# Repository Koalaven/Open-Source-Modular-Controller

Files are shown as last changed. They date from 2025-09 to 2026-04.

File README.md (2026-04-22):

# Open Source Modular Controller

Using a modular, reconfigurable hardware architecture to create a customizable USB HID game controller.

## Project Details

The Open Source Modular Controller project is a fully modular and customizable gaming input system. Users can freely rearrange joysticks, buttons, and future input modules on a set of interchangeable receiver boards to build a layout that fits their gameplay style, ergonomic needs, or accessibility requirements.

The controller connects over USB and is recognized as a standard Human Interface Device (HID) with no additional drivers required.



## Current State

The current prototype includes:
- A functional ESP32‑S3‑based main controller
- Hot-swappable joystick and button modules
- Receiver boards that can be placed anywhere in the 3D‑printed shell
- USB HID communication via TinyUSB

The system operates as a recognized USB gamepad on Windows. Some hardware issues were identified and corrected in updated revisions.

## Project Structure

The repository is organized as follows:
1. **Firmware** – ESP32‑S3 code handling HID communication and module input processing.  
   *Link: [Firmware](/Controller%20Code/Firmware.md)*
2. **Software** – PC‑side utilities or test scripts (coming soon).  
3. **Hardware** – KiCad project files, schematics, PCBs, and 3D‑printed shell models.  
   *Link: [Hardware](/Hardware/Hardware.md)*
4. **Documentation** – Assembly instructions, diagrams, semester report, and testing notes.  
   *Link: [Documentation](/Documents/Documents.md)*

## Features

- Modular input modules (buttons, joystick, future sensors)
- Repositionable input layout using multiple receiver boards
- ESP32‑S3 native USB HID support
- Open‑source hardware and firmware
- Premade 3D‑printable ergonomic controller shell

## System Architecture

Core system components include:
- **Receiver boards** distributing power, signals, and micro-controller
- **Module boards** for inputs (joystick/button)
- **3D‑printed enclosure** with heat‑set inserts for secure mounting

USB HID enumeration and report handling are implemented using TinyUSB. Modules communicate through standardized connectors to the controller board.

## Bill of Materials
A full BOM including the ESP32‑S3 boards, connector sets, resistors, capacitors, PCBs, wire, and 3D‑printed components is provided in the documentation.  
*[BOM](/Documents/BOM.md)*

## Tools Used
### Software
- Arduino IDE
- KiCad
- Fusion (frame design)
- GitHub Desktop
- Cura slicer

### Hardware
- 3D printer
- Soldering iron
- Hot air station
- Multimeter
- Tweezers

## Assembly Overview
1. Gather materials (refer to BOM).  
2. Order PCBs (Gerber files included).  
3. 3D print shell and module housings.  
4. Clean and prepare boards.  
5. Solder components (headers, ESP32 module, connectors, buttons/joysticks).  
6. Upload firmware via Arduino IDE.  
7. Install modules into the shell.  
8. Test controller.  

[Full assembly guide](/Documents/Assembly%20guide.md)

## What the Project Could Use Next
1. On‑board processing for more advanced input mapping
2. PCB adjustment and testing
3. Wireless mode using Bluetooth HID
4. Additional module types (battery, gyroscope, sliders, touchpads)

## Semester End Report
For the Enterprise Program at Michigan Tech there is a end of semester report for the project to summarize the progress of the project. [Link](/Documents/Open%20Source%20Modular%20Controller%20Fall%202025%20Final%20Report.pdf)

## Acknowledgements
This project is supported by the Open Source Hardware Enterprise at Michigan Technological University.

## Helpful Links
- [TinyUSB](https://docs.tinyusb.org/en/latest/)
- [Gamepad tester](https://hardwaretester.com/gamepad)

## References

[GitHub Doc](https://docs.github.com/en/get-started/writing-on-github/getting-started-with-writing-and-formatting-on-github/basic-writing-and-formatting-syntax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)

[Alpakka conroller](https://inputlabs.io/alpakka)

[Proteus ControllerTM kit](https://byowave.com/products/proteus-controller )

[Thrustmaster](https://eshop.thrustmaster.com/en_us/gamepads/pc.html)

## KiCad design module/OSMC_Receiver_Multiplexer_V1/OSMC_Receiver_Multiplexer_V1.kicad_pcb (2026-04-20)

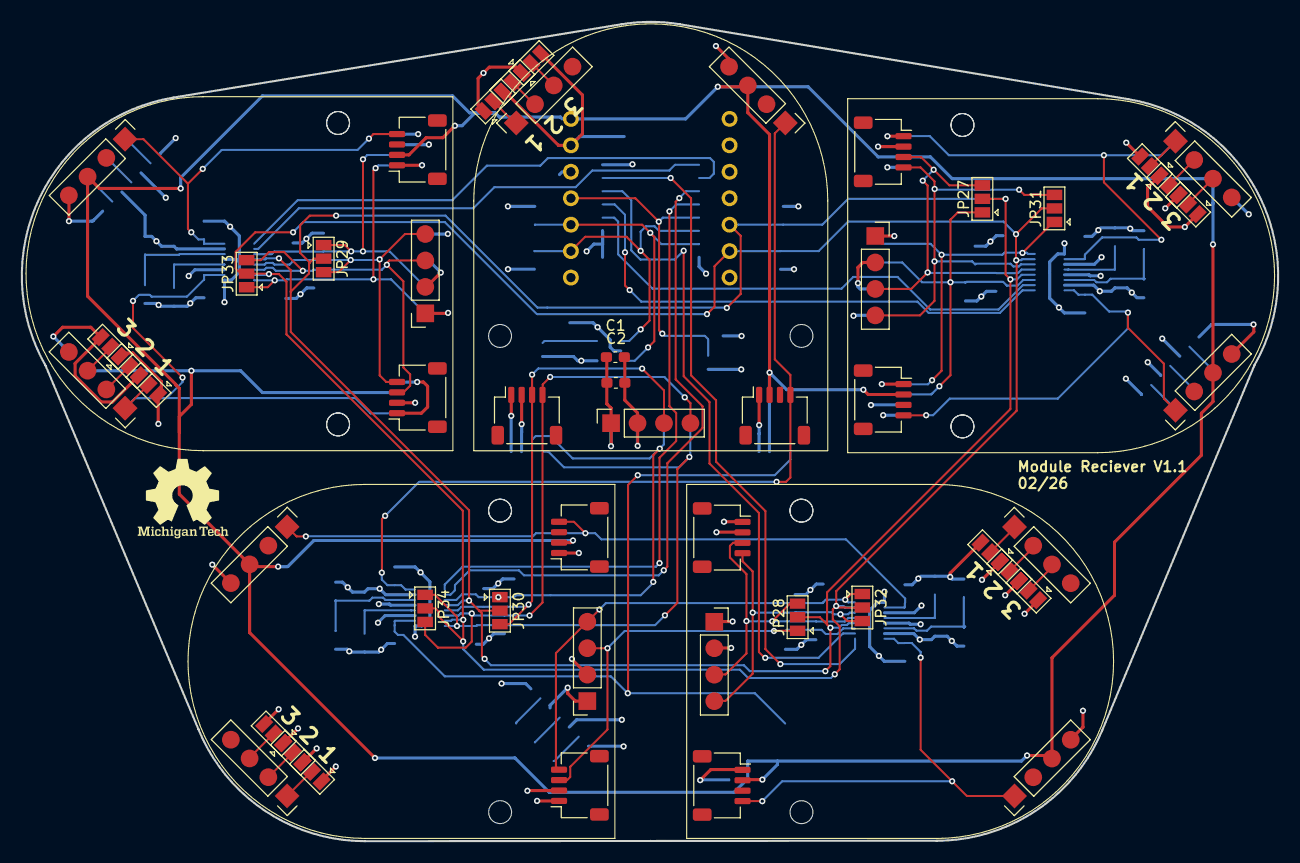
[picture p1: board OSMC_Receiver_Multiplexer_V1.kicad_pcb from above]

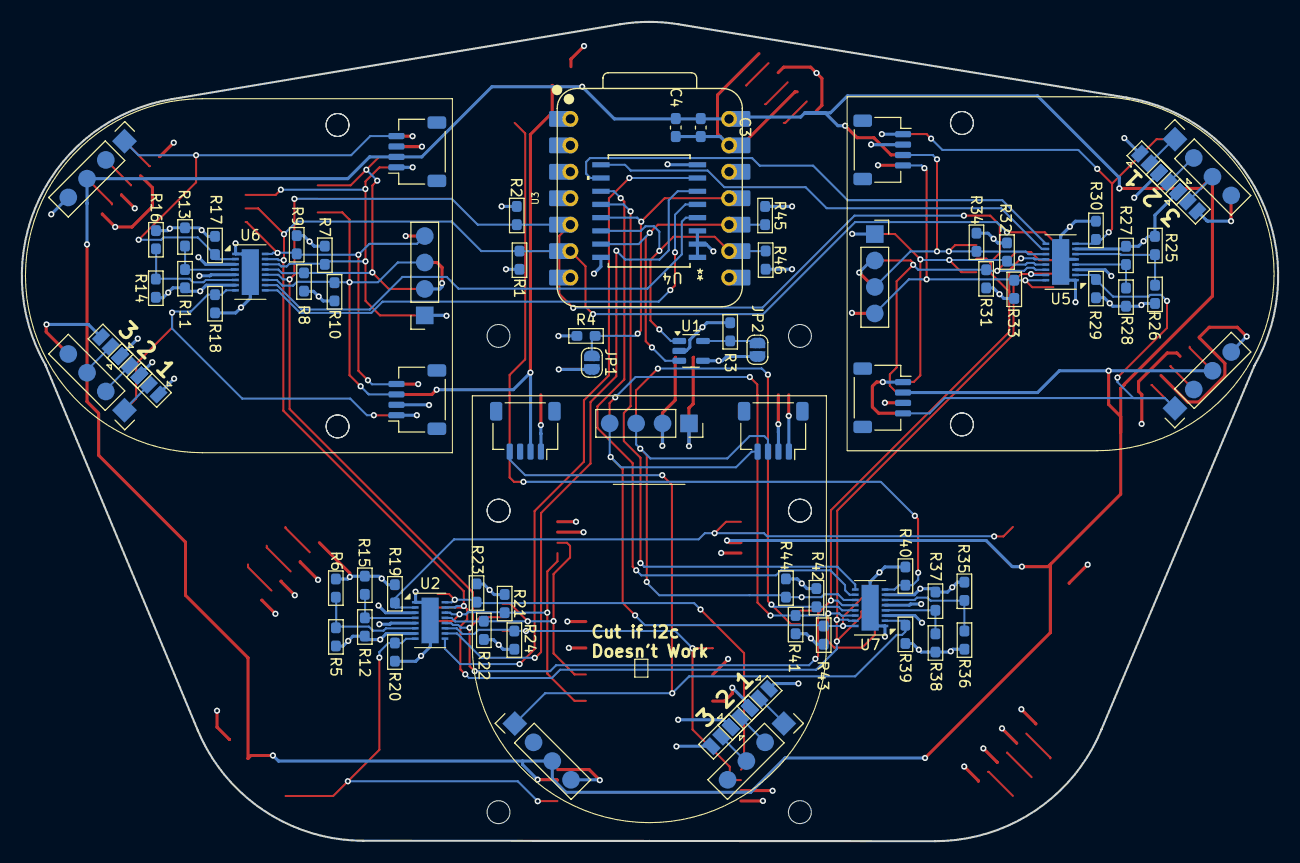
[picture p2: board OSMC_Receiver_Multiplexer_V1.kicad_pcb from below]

Board: 4 copper layers, 120.7 x 78.7 mm, 99 parts (69 on the bottom side), 73 nets.

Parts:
C1, C2: .1 u; C_0603_1608Metric_Pad1.08x0.95mm_HandSolder
C3, C4: C; C_0603_1608Metric_Pad1.08x0.95mm_HandSolder
JP1: int; SolderJumper-2_P1.3mm_Open_RoundedPad1.0x1.5mm
JP2: WP; SolderJumper-2_P1.3mm_Open_RoundedPad1.0x1.5mm
JP3, JP4, JP5, JP6, JP7, JP8, JP9, JP10, JP11, JP12, JP13, JP14, JP15, JP16, JP17, JP18, JP19, JP20, JP21, JP22, JP23, JP24, JP25, JP26, JP27, JP28, JP29, JP30, JP31, JP32, JP33, JP34: SolderJumper_3_Open; SolderJumper-3_P1.3mm_Open_Pad1.0x1.5mm
R1, R2, R7, R8, R9, R10, R17, R18, R19, R20, R21, R22, R23, R24, R29, R30, R31, R32, R33, R34, R39, R40, R41, R42, R43, R44, R45, R46: 10k; R_0603_1608Metric_Pad1.05x0.95mm_HandSolder
R3, R4: 100k; R_0603_1608Metric_Pad1.05x0.95mm_HandSolder
R5, R11: 976k; R_0603_1608Metric_Pad1.05x0.95mm_HandSolder
R6: 182k; R_0603_1608Metric_Pad1.05x0.95mm_HandSolder
R12: 1M; R_0603_1608Metric_Pad1.05x0.95mm_HandSolder
R13: 102k; R_0603_1608Metric_Pad1.05x0.95mm_HandSolder
R14: R; R_0603_1608Metric_Pad1.05x0.95mm_HandSolder
R15: 280k; R_0603_1608Metric_Pad1.05x0.95mm_HandSolder
R16: 0; R_0603_1608Metric_Pad1.05x0.95mm_HandSolder
R25, R27, R35, R37: 1000k; R_0603_1608Metric_Pad1.05x0.95mm_HandSolder
R26: 392k; R_0603_1608Metric_Pad1.05x0.95mm_HandSolder
R28: 523k; R_0603_1608Metric_Pad1.05x0.95mm_HandSolder
R36: 681k; R_0603_1608Metric_Pad1.05x0.95mm_HandSolder
R38: 887k; R_0603_1608Metric_Pad1.05x0.95mm_HandSolder
U1: 24AA02-OT; SOT-23-5
U2, U5, U6, U7: LTC4317; DFN-16-1EP_3x5mm_P0.5mm_EP1.66x4.4mm
U3: XIAO-ESP32-S3-DIP
U4: PCF8574DWR; DW16-L
U13, U14, U15, U16, U17, U18, U19, U20: OSMC Module Board; Module standard pin large outline

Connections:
+5V: C3.1, C4.1, U3.14 (5V), U13.10 (5V), U13.15 (5V), U14.10 (5V), U14.15 (5V), U15.10 (5V), U15.15 (5V), U16.10 (5V), U16.15 (5V), U17.10 (5V), U17.15 (5V), U18.10 (5V), U18.15 (5V), U19.10 (5V), U19.15 (5V), U20.10 (5V), U20.15 (5V)
/INT: JP1.1 (A), R4.2, U3.11 (PA6_A10_D10_MOSI), U4.13 (~INT)
/Modules/EN0: R18.2, U6.8 (ENABLE1), U13.12 (Det), U13.13 (Det)
/Modules/EN1: R17.2, U6.2 (ENABLE2), U15.12 (Det), U15.13 (Det)
/Modules/EN2: R20.2, U2.8 (ENABLE1), U16.12 (Det), U16.13 (Det)
/Modules/EN3: R19.2, U2.2 (ENABLE2), U18.12 (Det), U18.13 (Det)
/Modules/EN4: R30.2, U5.8 (ENABLE1), U17.12 (Det), U17.13 (Det)
/Modules/EN5: R29.2, U5.2 (ENABLE2), U20.12 (Det), U20.13 (Det)
/Modules/EN6: R40.2, U7.8 (ENABLE1), U14.12 (Det), U14.13 (Det)
/Modules/EN7: R39.2, U7.2 (ENABLE2), U19.12 (Det), U19.13 (Det)
/Modules/P0: U4.4 (P0), U6.10 (READY1)
/Modules/P1: U4.5 (P1), U6.9 (READY2)
/Modules/P2: U2.10 (READY1), U4.6 (P2)
/Modules/P3: U2.9 (READY2), U4.7 (P3)
/Modules/P4: U4.9 (P4), U5.10 (READY1)
/Modules/P5: U4.10 (P5), U5.9 (READY2)
/Modules/P6: U4.11 (P6), U7.10 (READY1)
/Modules/P7: U4.12 (P7), U7.9 (READY2)
/Modules/SCL0: JP31.3 (B), R7.2, U6.14 (SCLOUT1), U13.4 (SCL), U13.8 (SCL)
/Modules/SCL1: JP31.1 (A), R9.2, U6.16 (SCLOUT2), U15.4 (SCL), U15.8 (SCL)
/Modules/SCL2: JP32.3 (B), R21.2, U2.14 (SCLOUT1), U16.4 (SCL), U16.8 (SCL)
/Modules/SCL3: JP32.1 (A), R23.2, U2.16 (SCLOUT2), U18.4 (SCL), U18.8 (SCL)
/Modules/SCL4: JP33.3 (B), R31.2, U5.14 (SCLOUT1), U17.3 (SDA), U17.7 (SDA)
/Modules/SCL5: JP33.1 (A), R33.2, U5.16 (SCLOUT2), U20.4 (SCL), U20.8 (SCL)
/Modules/SCL6: JP34.3 (B), R41.2, U7.14 (SCLOUT1), U14.4 (SCL), U14.8 (SCL)
/Modules/SCL7: JP34.1 (A), R43.2, U7.16 (SCLOUT2), U19.4 (SCL), U19.8 (SCL)
/Modules/SDA0: JP27.3 (B), R8.2, U6.13 (SDAOUT1), U13.3 (SDA), U13.7 (SDA)
/Modules/SDA1: JP27.1 (A), R10.2, U6.11 (SDAOUT2), U15.3 (SDA), U15.7 (SDA)
/Modules/SDA2: JP28.3 (B), R22.2, U2.13 (SDAOUT1), U16.3 (SDA), U16.7 (SDA)
/Modules/SDA3: JP28.1 (A), R24.2, U2.11 (SDAOUT2), U18.3 (SDA), U18.7 (SDA)
/Modules/SDA4: JP29.3 (B), R32.2, U5.13 (SDAOUT1), U17.4 (SCL), U17.8 (SCL)
/Modules/SDA5: JP29.1 (A), R34.2, U5.11 (SDAOUT2), U20.3 (SDA), U20.7 (SDA)
/Modules/SDA6: JP30.3 (B), R42.2, U7.13 (SDAOUT1), U14.3 (SDA), U14.7 (SDA)
/Modules/SDA7: JP30.1 (A), R44.2, U7.11 (SDAOUT2), U19.3 (SDA), U19.7 (SDA)
/SCL: JP31.2 (C), JP32.2 (C), JP33.2 (C), JP34.2 (C), R1.2, U2.15 (SCLIN), U3.6 (PA9_A5_D5_SCL), U5.15 (SCLIN), U6.15 (SCLIN), U7.15 (SCLIN)
/SCL1: R46.2, U1.1 (SCL), U3.9 (PA7_A8_D8_SCK), U4.14 (SCL)
/SDA: JP27.2 (C), JP28.2 (C), JP29.2 (C), JP30.2 (C), R2.2, U2.12 (SDAIN), U3.5 (PA8_A4_D4_SDA), U5.12 (SDAIN), U6.12 (SDAIN), U7.12 (SDAIN)
/SDA1: R45.2, U1.3 (SDA), U3.10 (PA5_A9_D9_MISO), U4.15 (SDA)
/wp: JP2.1 (A), R3.2, U1.5 (WP)
GND: C1.2, C2.2, C3.2, C4.2, JP3.3 (B), JP4.3 (B), JP5.3 (B), JP6.3 (B), JP7.3 (B), JP8.3 (B), JP9.3 (B), JP10.3 (B), JP11.3 (B), JP12.3 (B), JP13.3 (B), JP14.3 (B), JP15.3 (B), JP16.3 (B), JP17.3 (B), JP18.3 (B), JP19.3 (B), JP20.3 (B), JP21.3 (B), JP22.3 (B), JP23.3 (B), JP24.3 (B), JP25.3 (B), JP26.3 (B), R3.1, R4.1, R6.2, R13.2, R15.2, R16.2, R17.1, R18.1, R19.1, R20.1, R26.2, R28.2, R29.1, R30.1, R36.2, R38.2, R39.1, R40.1, U1.2 (V_{SS}), U2.1 (GND), U2.3 (XORH2), U2.5 (XORH1), U2.17 (EP), U3.13 (GND), U4.1 (A0), U4.2 (A1), U4.3 (A2), U4.8 (GND), U5.1 (GND), U5.3 (XORH2), U5.5 (XORH1), U5.17 (EP), U6.1 (GND), U6.3 (XORH2), U6.5 (XORH1), U6.17 (EP), U7.1 (GND), U7.3 (XORH2), U7.5 (XORH1), U7.17 (EP), U13.1 (Gnd), U13.5 (Gnd), U13.9 (Gnd), U13.16 (GND), U14.1 (Gnd), U14.5 (Gnd), U14.9 (Gnd), U14.16 (GND), U15.1 (Gnd), U15.5 (Gnd), U15.9 (Gnd), U15.16 (GND), U16.1 (Gnd), U16.5 (Gnd), U16.9 (Gnd), U16.16 (GND), U17.1 (Gnd), U17.5 (Gnd), U17.9 (Gnd), U17.16 (GND), U18.1 (Gnd), U18.5 (Gnd), U18.9 (Gnd), U18.16 (GND), U19.1 (Gnd), U19.5 (Gnd), U19.9 (Gnd), U19.16 (GND), U20.1 (Gnd), U20.5 (Gnd), U20.9 (Gnd), U20.16 (GND)
unnamed: JP3.2 (C), U16.18 (A3)
unnamed: JP4.2 (C), U16.19 (A2)
unnamed: JP5.2 (C), U16.20 (A1)
unnamed: JP6.2 (C), U15.18 (A3)
unnamed: JP7.2 (C), U15.19 (A2)
unnamed: JP8.2 (C), U15.20 (A1)
unnamed: JP9.2 (C), U13.18 (A3)
unnamed: JP10.2 (C), U13.19 (A2)
unnamed: JP11.2 (C), U13.20 (A1)
unnamed: JP12.2 (C), U18.18 (A3)
unnamed: JP13.2 (C), U18.19 (A2)
unnamed: JP14.2 (C), U18.20 (A1)
unnamed: JP15.2 (C), U19.18 (A3)
unnamed: JP16.2 (C), U19.19 (A2)
unnamed: JP17.2 (C), U19.20 (A1)
unnamed: JP18.2 (C), U17.18 (A3)
unnamed: JP19.2 (C), U17.19 (A2)
unnamed: JP20.2 (C), U17.20 (A1)
unnamed: JP21.2 (C), U20.18 (A3)
unnamed: JP22.2 (C), U20.19 (A2)
unnamed: JP23.2 (C), U20.20 (A1)
unnamed: JP24.2 (C), U14.18 (A3)
unnamed: JP25.2 (C), U14.19 (A2)
unnamed: JP26.2 (C), U14.20 (A1)
unnamed: R5.2, R6.1, U2.6 (XORL1)
unnamed: R12.2, R15.1, U2.4 (XORL2)
unnamed: R25.2, R26.1, U5.6 (XORL1)
unnamed: R27.2, R28.1, U5.4 (XORL2)
unnamed: R14.2, R16.1, U6.6 (XORL1)
unnamed: R11.2, R13.1, U6.4 (XORL2)
unnamed: R35.2, R36.1, U7.6 (XORL1)
unnamed: R37.2, R38.1, U7.4 (XORL2)
VDD: C1.1, C2.1, JP1.2 (B), JP2.2 (B), JP3.1 (A), JP4.1 (A), JP5.1 (A), JP6.1 (A), JP7.1 (A), JP8.1 (A), JP9.1 (A), JP10.1 (A), JP11.1 (A), JP12.1 (A), JP13.1 (A), JP14.1 (A), JP15.1 (A), JP16.1 (A), JP17.1 (A), JP18.1 (A), JP19.1 (A), JP20.1 (A), JP21.1 (A), JP22.1 (A), JP23.1 (A), JP24.1 (A), JP25.1 (A), JP26.1 (A), R1.1, R2.1, R5.1, R7.1, R8.1, R9.1, R10.1, R11.1, R12.1, R14.1, R21.1, R22.1, R23.1, R24.1, R25.1, R27.1, R31.1, R32.1, R33.1, R34.1, R35.1, R37.1, R41.1, R42.1, R43.1, R44.1, R45.1, R46.1, U1.4 (V_{CC}), U2.7 (VCC), U3.12 (3V3), U4.16 (VDD), U5.7 (VCC), U6.7 (VCC), U7.7 (VCC), U13.2 (Vdd), U13.6 (Vdd), U14.2 (Vdd), U14.6 (Vdd), U15.2 (Vdd), U15.6 (Vdd), U16.2 (Vdd), U16.6 (Vdd), U17.2 (Vdd), U17.6 (Vdd), U18.2 (Vdd), U18.6 (Vdd), U19.2 (Vdd), U19.6 (Vdd), U20.2 (Vdd), U20.6 (Vdd)

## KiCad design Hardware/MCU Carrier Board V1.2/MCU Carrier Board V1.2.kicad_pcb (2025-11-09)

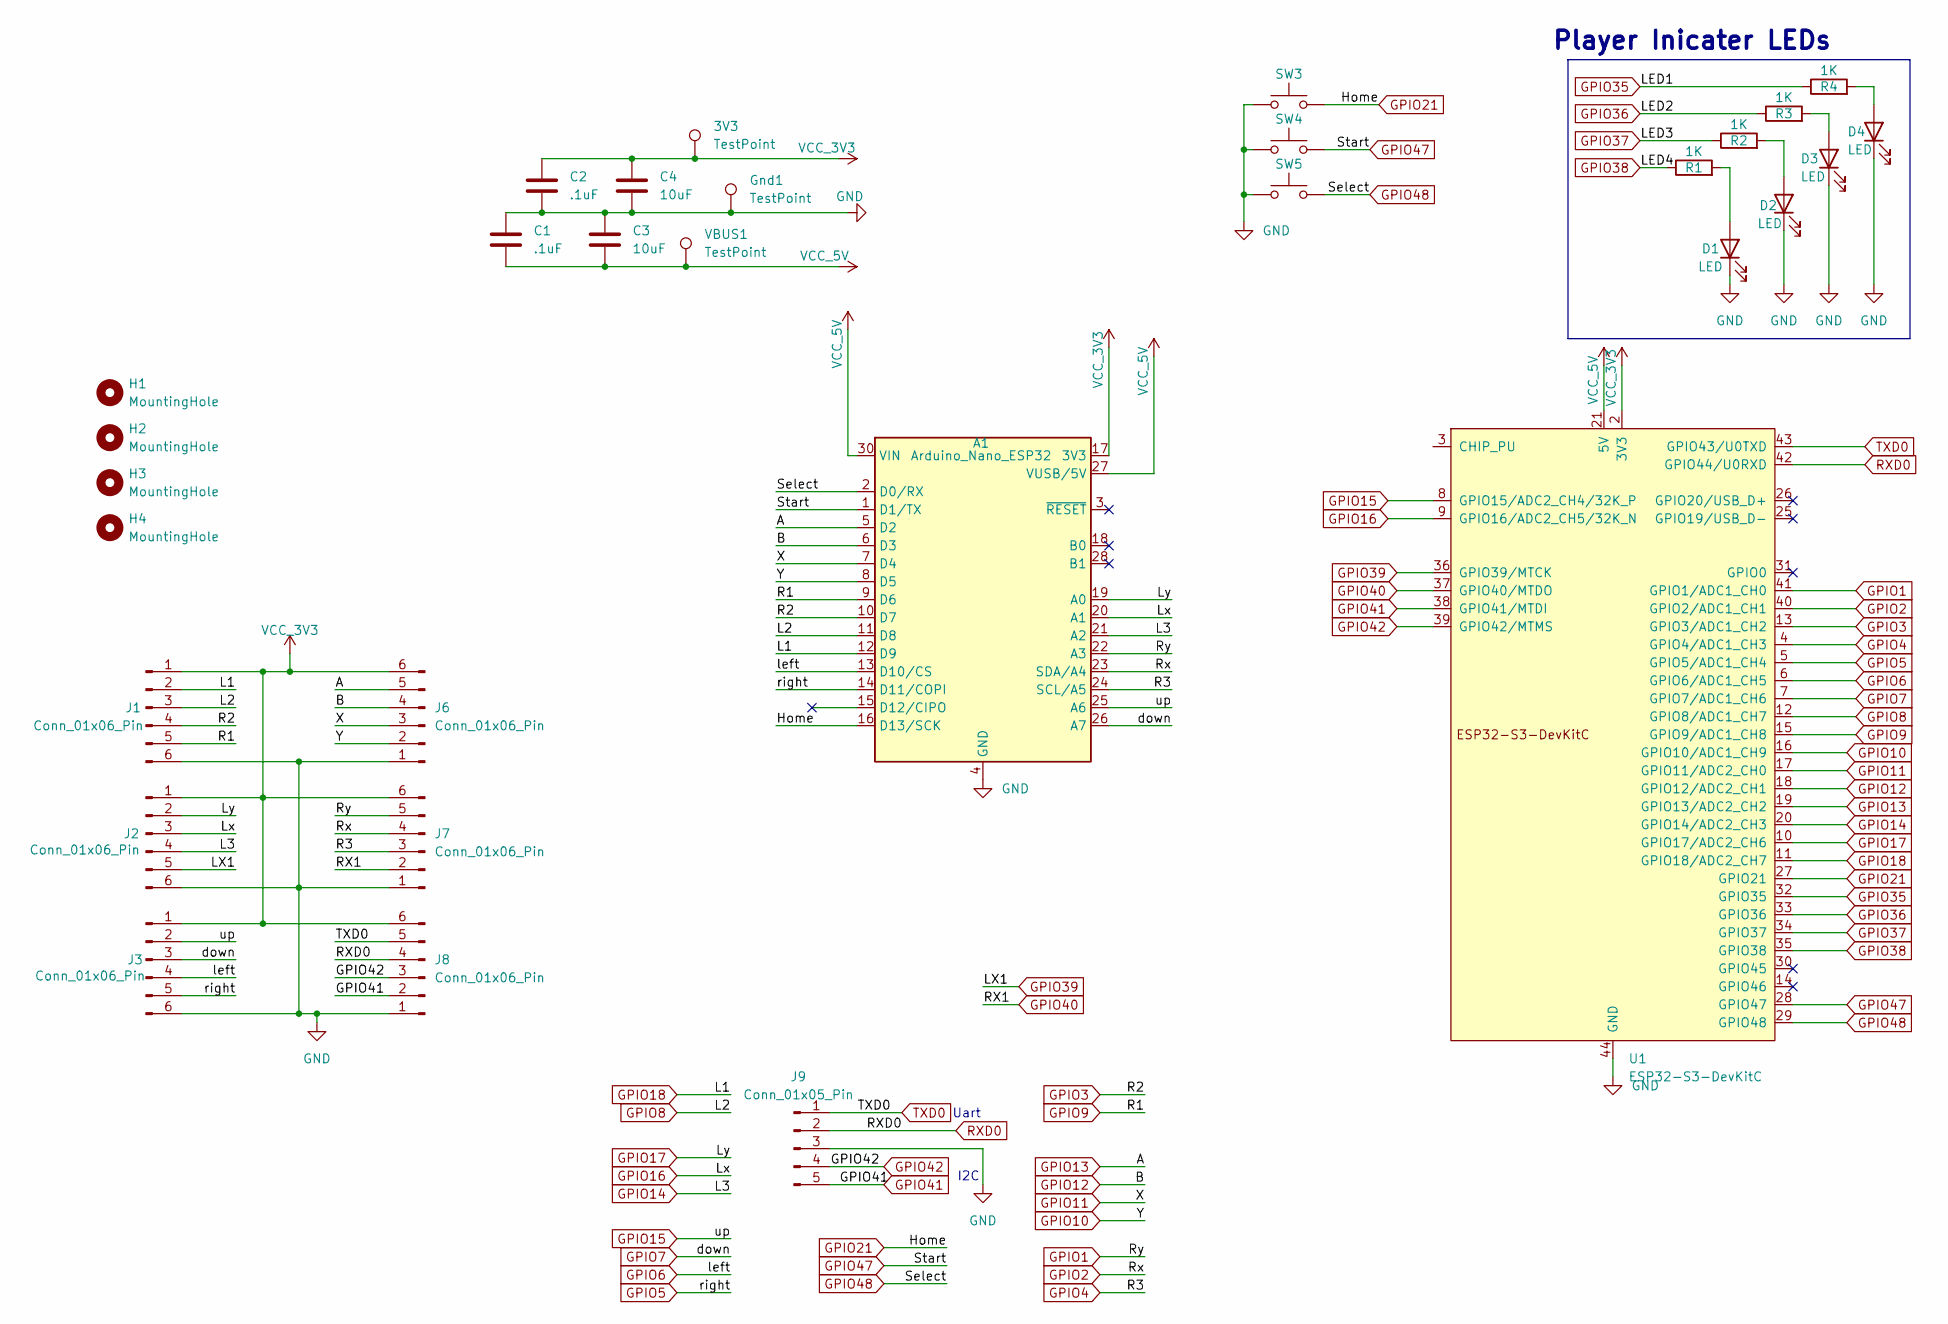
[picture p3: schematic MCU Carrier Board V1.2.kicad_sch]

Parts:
3V3: TestPoint; TestPoint_Pad_D1.0mm
A1: Arduino_Nano_ESP32; Arduino_Nano_WithMountingHoles
C1, C2: .1uF; C_0603_1608Metric_Pad1.08x0.95mm_HandSolder
C3, C4: 10uF; C_0603_1608Metric_Pad1.08x0.95mm_HandSolder
D1, D2, D3, D4: LED; LED_0603_1608Metric_Pad1.05x0.95mm_HandSolder
Gnd1: TestPoint; TestPoint_Pad_D1.0mm
H1, H2, H3, H4: MountingHole; MountingHole_2.5mm
J1, J2, J3, J6, J7, J8: Conn_01x06_Pin; PinHeader_1x06_P2.54mm_Vertical
J9: Conn_01x05_Pin; JST_EH_S5B-EH_1x05_P2.50mm_Horizontal
R1, R2, R3, R4: 1K; R_0603_1608Metric_Pad0.98x0.95mm_HandSolder
SW3, SW4, SW5: SW_Push; SW_Push_1P1T_XKB_TS-1187A
U1: ESP32-S3-DevKitC
VBUS1: TestPoint; TestPoint_Pad_D1.0mm

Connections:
GND: A1.4 (GND), A1.29 (GND), C1.1, C2.2, C3.1, C4.2, D1.1 (K), D2.1 (K), D3.1 (K), D4.1 (K), Gnd1.1, J1.6, J2.6, J3.6, J6.1, J7.1, J8.1, J9.3, SW3.1, SW4.1, SW5.1, U1.22 (GND), U1.23 (GND), U1.24 (GND), U1.44 (GND)
GPIO1: A1.22 (A3), J7.5, U1.41 (GPIO1/ADC1_CH0)
GPIO2: A1.23 (SDA/A4), J7.4, U1.40 (GPIO2/ADC1_CH1)
GPIO3: A1.10 (D7), J1.4, U1.13 (GPIO3/ADC1_CH2)
GPIO4: A1.24 (SCL/A5), J7.3, U1.4 (GPIO4/ADC1_CH3)
GPIO5: A1.14 (D11/COPI), J3.5, U1.5 (GPIO5/ADC1_CH4)
GPIO6: A1.13 (D10/CS), J3.4, U1.6 (GPIO6/ADC1_CH5)
GPIO7: A1.26 (A7), J3.3, U1.7 (GPIO7/ADC1_CH6)
GPIO8: A1.11 (D8), J1.3, U1.12 (GPIO8/ADC1_CH7)
GPIO9: A1.9 (D6), J1.5, U1.15 (GPIO9/ADC1_CH8)
GPIO10: A1.8 (D5), J6.2, U1.16 (GPIO10/ADC1_CH9)
GPIO11: A1.7 (D4), J6.3, U1.17 (GPIO11/ADC2_CH0)
GPIO12: A1.6 (D3), J6.4, U1.18 (GPIO12/ADC2_CH1)
GPIO13: A1.5 (D2), J6.5, U1.19 (GPIO13/ADC2_CH2)
GPIO14: A1.21 (A2), J2.4, U1.20 (GPIO14/ADC2_CH3)
GPIO15: A1.25 (A6), J3.2, U1.8 (GPIO15/ADC2_CH4/32K_P)
GPIO16: A1.20 (A1), J2.3, U1.9 (GPIO16/ADC2_CH5/32K_N)
GPIO17: A1.19 (A0), J2.2, U1.10 (GPIO17/ADC2_CH6)
GPIO18: A1.12 (D9), J1.2, U1.11 (GPIO18/ADC2_CH7)
GPIO21: A1.16 (D13/SCK), SW3.2, U1.27 (GPIO21)
GPIO35: R4.1, U1.32 (GPIO35)
GPIO36: R3.1, U1.33 (GPIO36)
GPIO37: R2.1, U1.34 (GPIO37)
GPIO38: R1.1, U1.35 (GPIO38)
GPIO39: J2.5, U1.36 (GPIO39/MTCK)
GPIO40: J7.2, U1.37 (GPIO40/MTDO)
GPIO41: J8.2, J9.5, U1.38 (GPIO41/MTDI)
GPIO42: J8.3, J9.4, U1.39 (GPIO42/MTMS)
GPIO47: A1.1 (D1/TX), SW4.2, U1.28 (GPIO47)
GPIO48: A1.2 (D0/RX), SW5.2, U1.29 (GPIO48)
unnamed: D1.2 (A), R1.2
unnamed: D2.2 (A), R2.2
unnamed: D3.2 (A), R3.2
unnamed: D4.2 (A), R4.2
RXD0: J8.4, J9.2, U1.42 (GPIO44/U0RXD)
TXD0: J8.5, J9.1, U1.43 (GPIO43/U0TXD)
VCC_3V3: 3V3.1, A1.17 (3V3), C2.1, C4.1, J1.1, J2.1, J3.1, J6.6, J7.6, J8.6, U1.1 (3V3), U1.2 (3V3)
VCC_5V: A1.27 (VUSB/5V), A1.30 (VIN), C1.2, C3.2, U1.21 (5V), VBUS1.1

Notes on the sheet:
Player Inicater LEDs
Uart
I2C

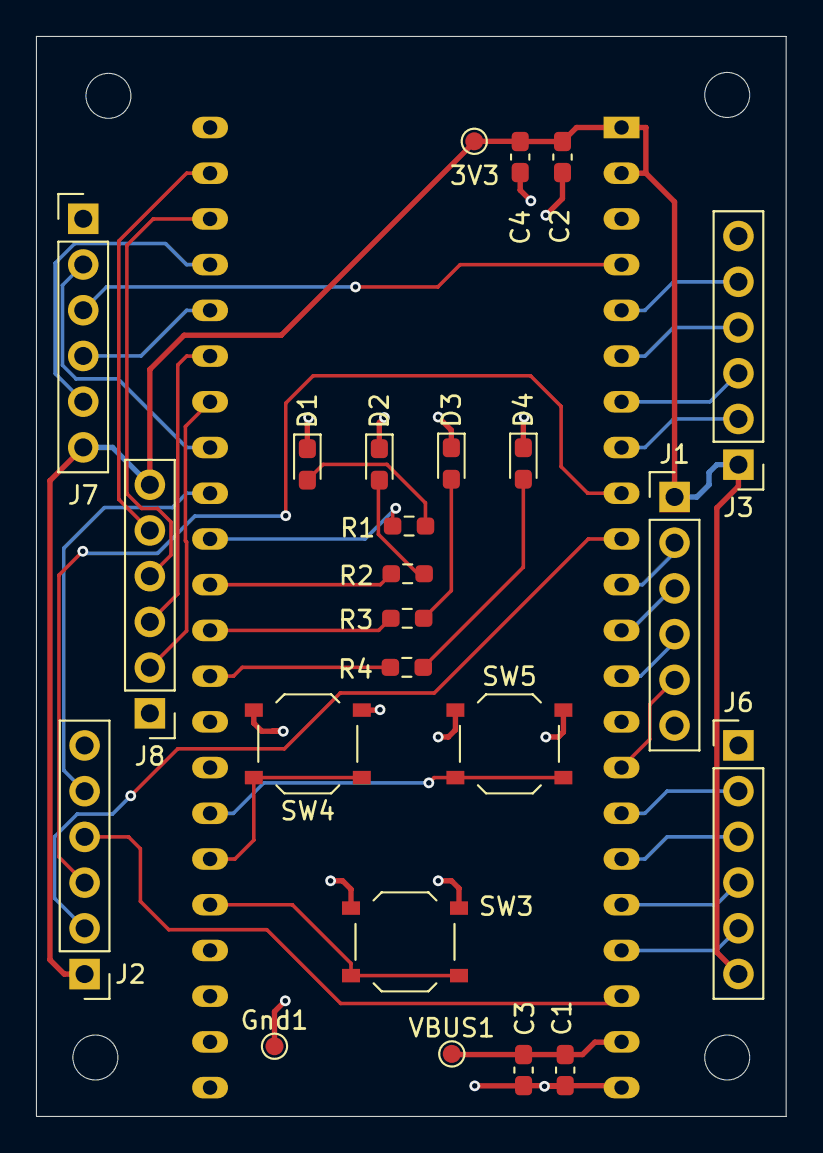
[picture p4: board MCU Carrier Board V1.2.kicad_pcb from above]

Board: 2 copper layers, 41.7 x 60.0 mm, 29 parts (1 on the bottom side), 38 nets.

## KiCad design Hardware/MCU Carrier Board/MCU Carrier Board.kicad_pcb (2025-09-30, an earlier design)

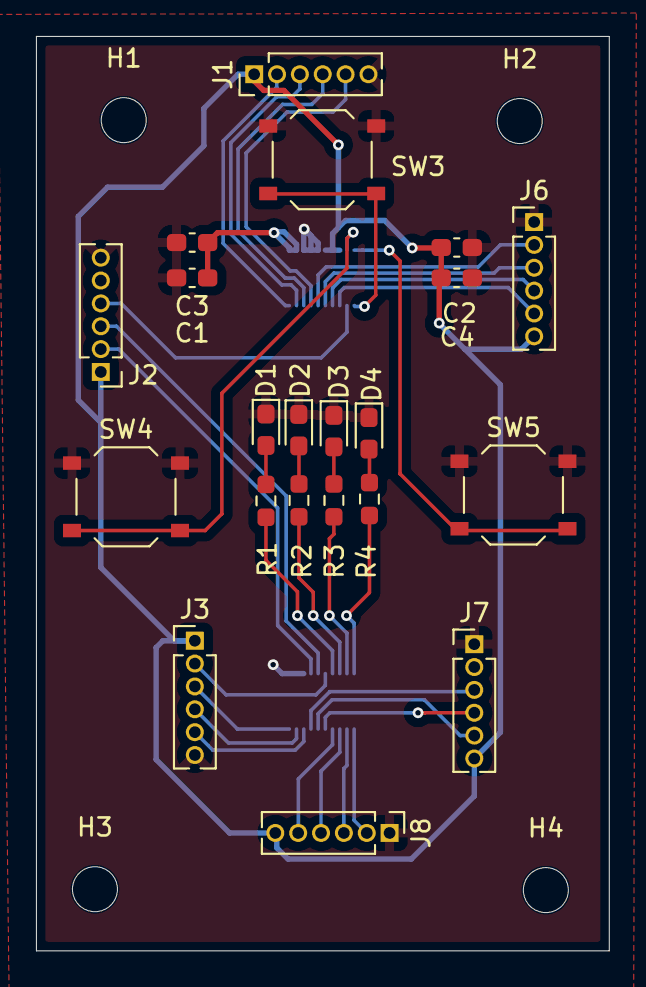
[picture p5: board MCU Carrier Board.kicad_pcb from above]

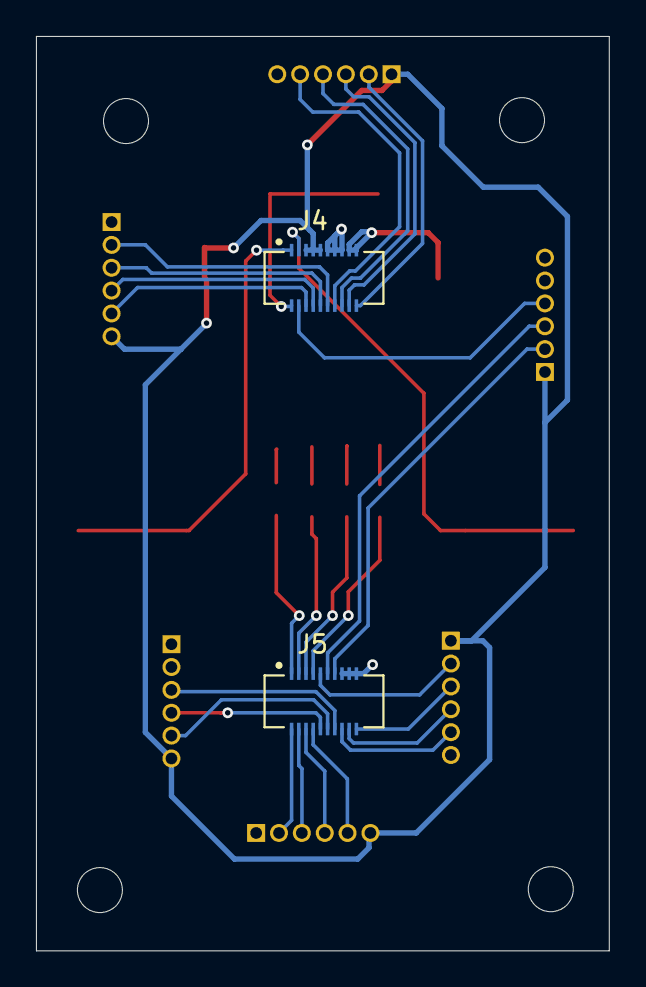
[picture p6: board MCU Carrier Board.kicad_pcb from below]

Board: 2 copper layers, 31.8 x 50.8 mm, 27 parts (2 on the bottom side), 36 nets.

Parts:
C1, C2: .1uF; C_0603_1608Metric_Pad1.08x0.95mm_HandSolder
C3, C4: 10uF; C_0603_1608Metric_Pad1.08x0.95mm_HandSolder
D1, D2, D3, D4: LED; LED_0603_1608Metric_Pad1.05x0.95mm_HandSolder
H1, H2, H3, H4: MountingHole; MountingHole_2.5mm
J1, J2, J3, J6, J7, J8: Conn_01x06_Pin; PinHeader_1x06_P1.27mm_Vertical
J4: Top Connector; HRS_DF40C-20DS-0.4V_51_
J5: Bottom Connector; HRS_DF40C-20DS-0.4V_51_
R1, R2, R3, R4: 1K; R_0603_1608Metric_Pad0.98x0.95mm_HandSolder
SW3, SW4, SW5: SW_Push; SW_Push_1P1T_XKB_TS-1187A

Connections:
GND: C1.1, C2.2, C3.1, C4.2, D1.1 (K), D2.1 (K), D3.1 (K), D4.1 (K), J1.6, J2.6, J3.6, J4.11, J4.13, J4.15, J5.15, J5.17, J5.19, J6.1, J7.1, J8.1, SW3.1, SW4.1, SW5.1
GPIO1: J5.12, J7.5
GPIO2: J5.10, J7.4
GPIO3: J1.4, J4.16
GPIO4: J5.14, J7.3
GPIO5: J3.5, J5.16
GPIO6: J3.4, J5.18
GPIO7: J3.3, J5.20
GPIO8: J1.3, J4.18
GPIO9: J1.5, J4.14
GPIO10: J4.12, J6.2
GPIO11: J4.10, J6.3
GPIO12: J4.8, J6.4
GPIO13: J4.6, J6.5
GPIO14: J2.4, J4.4
GPIO15: J3.2, J5.9
GPIO16: J2.3, J5.11
GPIO17: J2.2, J5.13
GPIO18: J1.2, J4.20
GPIO21: J4.2, SW3.2
GPIO35: J5.1, R4.1
GPIO36: J5.3, R3.1
GPIO37: J5.5, R2.1
GPIO38: J5.7, R1.1
GPIO41: J5.2, J8.2
GPIO42: J5.4, J8.3
GPIO47: J4.3, SW4.2
GPIO48: J4.1, SW5.2
unnamed: D1.2 (A), R1.2
unnamed: D2.2 (A), R2.2
unnamed: D3.2 (A), R3.2
unnamed: D4.2 (A), R4.2
RXD0: J5.6, J8.4
TXD0: J5.8, J8.5
VCC_3V3: C2.1, C4.1, J1.1, J2.1, J3.1, J4.5, J4.7, J4.9, J6.6, J7.6, J8.6
VCC_5V: C1.2, C3.2, J4.17, J4.19

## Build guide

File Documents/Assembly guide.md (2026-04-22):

# Assembly Instructions

## 1. Gather Materials

* Refer to the **Bill of Materials (BOM)**.
* Download the main GitHub repository branch: [link](https://github.com/OSHE-Github/Open-Source-Modular-Controller/tree/main).

---

## 2. Order PCBs

1. Use a PCB manufacturer of your choice.
2. Gerber files are provided in the GitHub repository: [link](/Hardware/PCBs/gerber%20files/).
3. Boards can be ordered fully assembled or as bare PCBs.
4. Two versions exist:

   * **Custom ESP32 carrier board**
   * **ESP32-S3 DevKitC-based interposer board** (used in the shell design)

---

## 3. 3D Print the Shell

For Our Shells:
1. Body shells: [link](/Hardware/Shell/OSMC)
    - The full casing can be printed from the .step file
    - Individual case sections can be printed from the .stl files
2. Module shells: [link](/Hardware/Module%STLs)
    - Standard configurations require **7** modules: 1 Master, 2 Bumpers, 2 Joysticks, 2 Buttons
    - Each **Master** modules requires: 1 Master top casing, 1 Master bottom casing, 3 Master buttons
    - Each **Joystick** module requires: 1 Joystick top casing, 1 Joystick bottom casing
    - Each **Bumper** module requires 1 Bumper body casing and 2 Bumper caps
    - Each **Button** module requires: 1 Button top casing, 1 Button Bottom casing, 4 non-Master buttons
        - For push buttons, options include the normal button caps ([link](/Hardware/Module%STLs/OSMC_Module_Buttons_Button)) and the taller button caps ([link](/Hardware/Module%STLs/Button%Cap%Taller.stl))
        - For membrane buttons, print the SMD caps ([link](/Hardware/Module%STLs/Button%Cap$SMD.stl))
    
For **Custom** shell designs we recommend following this design process: [link](/Documents/Custom%Shell%Recommendations.md)

---

## 4. Prep the PCBs

1. **Sand** the edges to clean rough PCB cuts.
2. **Clean** with isopropyl alcohol to remove oils and residue.

---

## 5. Solder Components

Most boards in this build were hand-soldered.

### 5a. Custom ESP32-S3 Board

1. Solder **headers** on the bottom side.
2. Add remaining bottom-side components from lowest profile upward.
3. Solder the **USB port** using flux and wick.
4. Attach the **ESP32-S3 module**:

   * Pre-tin both board pads and module pads.
   * Heat with hot air until alignment occurs.
   * Hold lightly with tweezers if needed.

---

### 5b. Receiver Modules

1. Solder **female headers** at J1–J4.
2. Solder **26 AWG stranded wires** at J5 in this order (bottom → top):
   **Black – Red – Blue – Green – White – Yellow**.
3. Repeat wiring for all receiver boards.

---

### 5c. Dev Board Carrier

1. Insert headers into the ESP32 DevKit board and solder the carrier board on top.
2. Add push **buttons**.
3. Solder module wires in this order (top → bottom):
   **Red – Blue – Yellow – White – Green – Black**.

---

### 5d. Custom ESP Interposer

1. Solder header sockets.
2. Add remaining components.
   *(LEDs and their resistors are optional in this version.)*

---

### 5e. Joystick Modules

1. Solder joystick into labeled pads.
2. Insert and solder **male pin headers** on the opposite side.
3. Verify solder joints and joystick button clearance.
4. Place PCB into joystick shell and mark **up direction**.
5. Glue the top cover to the shell.

---

### 5f. Button Modules

1. Solder four push-buttons into labeled positions.
2. Insert and solder **male pin headers** on the opposite side.
3. Confirm button movement is unobstructed.
4. Place module in shell and mark **up direction**.
5. Glue the top plate onto the shell.

---

## 6. Upload Firmware

1. Install **Arduino IDE**.
2. Add ESP32 board manager URL in Preferences:
   `https://espressif.github.io/arduino-esp32/package_esp32_index.json`
3. Install the **ESP32 board package**.
4. Install **ESP32TinyUSB** library.
5. Import project files.
6. Connect via USB (UART port).
7. Select:
   * **ESP32-S3 Dev Module**
   * Proper **COM port**
8. Adjust other board settings as documented.
9. Compile and upload firmware.
10. Use **UART** for programming and **USB** for HID operation.

---

## 7. Assemble the Controller Shell

1. Place Receiver boards in the main shell.
2. Mark screw hole locations.
4. Install **M3 heat-set inserts** at marked points.
5. Repeat steps **1-3** instead with the Bumper modules
6. Connect the Bumper modules to the back of the Receiver board using the **JST** connectors
7. Screw Receiver board and Bumper modules into place.
8. Insert the **ESP-32** into the pin connectors on the bottom of the Receiver board
9. Set Button, Joystick, and Master modules on their respective pogo pins following the screenprint's outline
10. Place the shell's top plate over the modules, while verifying their alignment
11. Slide the shell's bottom plate into place

Note: To rearrange the top modules, carefully push up on the tab of the top plate, and repeat steps 8-9 with the new configuration

---

## 8. Testing

1. Plug the controller with the USB port
2. Use an online tester such as [Gamepad tester](https://hardwaretester.com/gamepad).
3. Verify:

   * All buttons register
   * Joystick axes update smoothly
   * No shorts or missed inputs

If issues occur, check soldering, wiring order, and continuity.

---

**Your controller is now fully assembled and ready for use!**

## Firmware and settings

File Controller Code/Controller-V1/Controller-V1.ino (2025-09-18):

/**
 * Simple HID gamepad, 32 buttons + 2x 3 axis + 8 position hat
 * author: chegewara
 * library used ESP32TinyUSB
 */
#define PIN_Rx 1
#define PIN_Ry 2
#define Lx 4
#define Ly 5

#define R1 17
#define L1 18
#define R2 3
#define L2 6
#define R3 15
#define L3 16

#define A 7
#define B 8
#define X 9
#define Y 10

#define up 11
#define down 12
#define left 13
#define right 14

#define START 35
#define SELECT 36
#define HOME 21

const int deadzone = 9;
const int polldelay = 10;

#include "hidgamepad.h"
#if CFG_TUD_HID
HIDgamepad gamepad;

void setup()
{
    pinMode(PIN_Ry, INPUT);
    pinMode(PIN_Rx, INPUT);
    pinMode(Ly, INPUT);
    pinMode(Lx, INPUT);

    pinMode(R1,  INPUT_PULLUP); 
    pinMode(L1,  INPUT_PULLUP); 
    pinMode(R2,  INPUT_PULLUP); 
    pinMode(L2,  INPUT_PULLUP);   
    pinMode(R3,  INPUT_PULLUP); 
    pinMode(L3,  INPUT_PULLUP);

    pinMode(A,  INPUT_PULLUP);
    pinMode(B,  INPUT_PULLUP);
    pinMode(X,  INPUT_PULLUP); 
    pinMode(Y,  INPUT_PULLUP);

    pinMode(up,  INPUT_PULLUP); 
    pinMode(down,  INPUT_PULLUP); 
    pinMode(left,  INPUT_PULLUP); 
    pinMode(right,  INPUT_PULLUP);
 
    pinMode(START,  INPUT_PULLUP); 
    pinMode(SELECT,  INPUT_PULLUP); 
    pinMode(HOME,  INPUT_PULLUP); 

    Serial.begin(115200);
    gamepad.begin();
}

void loop()
{
    // -------------------
    // Read analog joysticks
    // -------------------
    // Map ADC values (0–4095 on ESP32) to HID range (-127..127)
    int lxVal = map(analogRead(Lx), 0, 4095, -127, 127);
    if (abs(lxVal)<deadzone){
        lxVal=0;
    }
    int lyVal = map(analogRead(Ly), 0, 4095, -127, 127);
    if (abs(lyVal)<deadzone){
        lyVal=0;
    }
    int rxVal = map(analogRead(PIN_Rx), 0, 4095, -127, 127);
    if (abs(rxVal)<deadzone){
        rxVal=0;
    }
    int ryVal = map(analogRead(PIN_Ry), 0, 4095, -127, 127);
    if (abs(ryVal)<deadzone){
        ryVal=0;
    }
    
    // Triggers (if you want them analog, otherwise treat as buttons)
    
    int l2Val = !digitalRead(L2) ? 127 : 0;
    int r2Val = !digitalRead(R2) ? 127 : 0;

    // -------------------
    // Read buttons
    // -------------------
    uint32_t buttons = 0;

    if (!digitalRead(A))     buttons |= (1 << 0);
    if (!digitalRead(B))     buttons |= (1 << 1);
    if (!digitalRead(X))     buttons |= (1 << 2);
    if (!digitalRead(Y))     buttons |= (1 << 3);

    if (!digitalRead(R1))    buttons |= (1 << 4);
    if (!digitalRead(L1))    buttons |= (1 << 5);
    if (!digitalRead(R3))    buttons |= (1 << 6);
    if (!digitalRead(L3))    buttons |= (1 << 7);

    if (!digitalRead(START)) buttons |= (1 << 8);
    if (!digitalRead(SELECT))buttons |= (1 << 9);
    if (!digitalRead(HOME))  buttons |= (1 << 10);

    // -------------------
    // Read D-pad → hat
    // -------------------
    uint8_t hat = 0; // default center
    if (!digitalRead(up) && !digitalRead(right))  hat = 2; // up-right
    else if (!digitalRead(up) && !digitalRead(left))  hat = 8; // up-left
    else if (!digitalRead(down) && !digitalRead(right)) hat = 4; // down-right
    else if (!digitalRead(down) && !digitalRead(left))  hat = 6; // down-left
    else if (!digitalRead(up))    hat = 1;
    else if (!digitalRead(right)) hat = 3;
    else if (!digitalRead(down))  hat = 5;
    else if (!digitalRead(left))  hat = 7;

    // -------------------
    // Send state to HID
    // -------------------
    gamepad.sendAll(
        buttons,   // 32 buttons bitmask
        lxVal,     // LX
        lyVal,     // LY
        l2Val,     // L2 (treated as analog axis)
        rxVal,     // RX
        ryVal,     // RY
        r2Val,     // R2 (treated as analog axis)
        hat        // D-pad hat
    );
    Serial.println("Joystick position");
    Serial.printf( "Left y: %d x: %d \nRight y: %d x: %d \n", lyVal,lxVal,ryVal,rxVal);
    Serial.printf("Button State A B X Y R1 L1 R2 L2 R3 L3 \n%d \n", buttons);
    Serial.printf("Hat position: %d \n", hat);

    delay(polldelay); // Small poll delay
}

#endif

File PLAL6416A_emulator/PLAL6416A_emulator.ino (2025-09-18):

/*
   PCAL6416A Emulator for ESP32 Nano (Arduino version)
   ---------------------------------------------------
   - Emulates PCAL6416A 16-bit I/O expander
   - I2C slave at address 0x20
   - Inputs & registers controlled via Serial commands:
       I0 XX        -> set Input Port 0 (0x00) to hex value XX
       I1 XX        -> set Input Port 1 (0x01) to hex value XX
       REG AA XX    -> set register AA to value XX
       READ AA      -> read register AA
       SHOW         -> print key registers (inputs & outputs)
       DUMP         -> print all registers 0x00–0x4F
       HELP         -> show this command list
*/

#include <Wire.h>
#include <Arduino.h>

#define I2C_ADDR  0x20
#define INT_PIN   10   // INT output pin (active LOW)

static uint8_t regs[0x50];
static uint8_t pointer_reg = 0x00;
static bool pointer_valid = false;

static uint8_t prev_input0 = 0, prev_input1 = 0;
static uint8_t latched_input0 = 0, latched_input1 = 0;

// ===== Reset defaults =====
void init_registers() {
  memset(regs, 0, sizeof(regs));
  regs[0x02] = regs[0x03] = 0xFF;  // outputs default high
  regs[0x06] = regs[0x07] = 0xFF;  // all pins input
  regs[0x40] = regs[0x41] = regs[0x42] = regs[0x43] = 0xFF;
  regs[0x48] = regs[0x49] = 0xFF;
  regs[0x4A] = regs[0x4B] = 0xFF;  // all masked
  regs[0x4F] = 0x00;               // push-pull

  prev_input0 = regs[0x00];
  prev_input1 = regs[0x01];
  latched_input0 = latched_input1 = 0;

  digitalWrite(INT_PIN, HIGH); // release INT
}

static uint8_t next_reg(uint8_t reg) {
  switch (reg) {
    case 0x00: return 0x01; case 0x01: return 0x00;
    case 0x02: return 0x03; case 0x03: return 0x02;
    case 0x04: return 0x05; case 0x05: return 0x04;
    case 0x06: return 0x07; case 0x07: return 0x06;
    case 0x40: return 0x41; case 0x41: return 0x40;
    case 0x42: return 0x43; case 0x43: return 0x42;
    case 0x44: return 0x45; case 0x45: return 0x44;
    case 0x46: return 0x47; case 0x47: return 0x46;
    case 0x48: return 0x49; case 0x49: return 0x48;
    case 0x4A: return 0x4B; case 0x4B: return 0x4A;
    case 0x4C: return 0x4D; case 0x4D: return 0x4C;
    default:   return reg + 1;
  }
}

// ===== Interrupt update =====
static void update_interrupt() {
  uint8_t input0 = regs[0x00], input1 = regs[0x01];
  uint8_t mask0  = regs[0x4A], mask1  = regs[0x4B];
  uint8_t latch0 = regs[0x44], latch1 = regs[0x45];

  uint8_t changed0 = (input0 ^ prev_input0) & ~mask0;
  uint8_t changed1 = (input1 ^ prev_input1) & ~mask1;

  if (latch0) latched_input0 |= changed0; else latched_input0 = changed0;
  if (latch1) latched_input1 |= changed1; else latched_input1 = changed1;

  regs[0x4C] = latched_input0;
  regs[0x4D] = latched_input1;

  digitalWrite(INT_PIN, (latched_input0 || latched_input1) ? LOW : HIGH);
}

// ===== Clear interrupt on read =====
static void clear_interrupt_on_read(uint8_t reg) {
  if (reg == 0x00 || reg == 0x01) {
    prev_input0 = regs[0x00];
    prev_input1 = regs[0x01];
    latched_input0 = latched_input1 = 0;
    regs[0x4C] = regs[0x4D] = 0;
    digitalWrite(INT_PIN, HIGH);
  }
}

// ===== I2C callbacks =====
void onReceive(int howMany) {
  if (howMany <= 0) return;
  uint8_t first = Wire.read();
  howMany--;
  if (howMany == 0) { pointer_reg = first; pointer_valid = true; return; }
  pointer_reg = first; pointer_valid = true;
  while (howMany-- > 0) {
    uint8_t val = Wire.read();
    if (!(pointer_reg == 0x00 || pointer_reg == 0x01 ||
          pointer_reg == 0x4C || pointer_reg == 0x4D)) {
      regs[pointer_reg] = val;
    }
    pointer_reg = next_reg(pointer_reg);
  }
  update_interrupt();
}

void onRequest() {
  if (!pointer_valid) pointer_reg = 0;
  uint8_t val = regs[pointer_reg];
  Wire.write(val);
  //clear_interrupt_on_read(pointer_reg);
  pointer_reg = next_reg(pointer_reg);
}

// ===== Command list printer =====
void printHelp() {
  Serial.println("Available commands:");
  Serial.println("  I0 XX       - Set Input Port 0 (0x00) to hex value XX");
  Serial.println("  I1 XX       - Set Input Port 1 (0x01) to hex value XX");
  Serial.println("  REG AA XX   - Set register AA to hex value XX");
  Serial.println("  READ AA     - Read register AA");
  Serial.println("  SHOW        - Show inputs and outputs");
  Serial.println("  DUMP        - Dump all registers 0x00–0x4F");
  Serial.println("  HELP        - Show this list");
}

// ===== Serial command parser =====
void handleSerial() {
  if (Serial.available()) {
    String line = Serial.readStringUntil('\n');
    line.trim();
    if (line.startsWith("I0")) {
      int val = strtol(line.substring(3).c_str(), NULL, 16);
      regs[0x00] = val & 0xFF;
      Serial.printf("Input Port 0 (0x00) set to 0x%02X\n", regs[0x00]);
      update_interrupt();
    } else if (line.startsWith("I1")) {
      int val = strtol(line.substring(3).c_str(), NULL, 16);
      regs[0x01] = val & 0xFF;
      Serial.printf("Input Port 1 (0x01) set to 0x%02X\n", regs[0x01]);
      update_interrupt();
    } else if (line.startsWith("REG")) {
      int addr, val;
      if (sscanf(line.c_str(), "REG %x %x", &addr, &val) == 2) {
        if (addr >= 0 && addr < sizeof(regs)) {
          regs[addr] = val & 0xFF;
          Serial.printf("Register 0x%02X set to 0x%02X\n", addr, regs[addr]);
          update_interrupt();
        } else {
          Serial.println("Error: Invalid register address");
        }
      } else {
        Serial.println("Usage: REG <addr> <val> (hex)");
      }
    } else if (line.startsWith("READ")) {
      int addr;
      if (sscanf(line.c_str(), "READ %x", &addr) == 1) {
        if (addr >= 0 && addr < sizeof(regs)) {
          Serial.printf("Register 0x%02X = 0x%02X\n", addr, regs[addr]);
        } else {
          Serial.println("Error: Invalid register address");
        }
      } else {
        Serial.println("Usage: READ <addr> (hex)");
      }
    } else if (line.startsWith("SHOW")) {
      Serial.printf("Inputs: P0=0x%02X P1=0x%02X | Outputs: P0=0x%02X P1=0x%02X\n",
                    regs[0x00], regs[0x01], regs[0x02], regs[0x03]);
    } else if (line.startsWith("DUMP")) {
      Serial.println("Register dump:");
      for (int i = 0; i < 0x50; i++) {
        Serial.printf("0x%02X: 0x%02X\t", i, regs[i]);
        if ((i % 8) == 7) Serial.println();
      }
    } else if (line.startsWith("HELP")) {
      printHelp();
    } else {
      Serial.println("Unknown command. Type HELP for list of commands.");
    }
  }
}

// ===== Setup / Loop =====
void setup() {
  pinMode(INT_PIN, OUTPUT);
  digitalWrite(INT_PIN, HIGH);
  init_registers();

  Wire.begin(I2C_ADDR);   // join I2C bus as slave
  Wire.onReceive(onReceive);
  Wire.onRequest(onRequest);

  Serial.begin(115200);
  while (!Serial) {}
  Serial.println("ESP32 Nano PCAL6416A Emulator started (Serial inputs)");
  printHelp();
}

void loop() {
  handleSerial();
}

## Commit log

2025-09-26 starting board
    [MCU Carrier Board.kicad_pcb, MCU Carrier Board.kicad_sch]
2025-09-26 added outline
    [MCU Carrier Board.kicad_pcb]
2025-09-30 locked placement of key components
    [MCU Carrier Board.kicad_pcb, MCU Carrier Board.kicad_sch]
2025-09-30 reconfigured pins and started routing
    [MCU Carrier Board.kicad_pcb, MCU Carrier Board.kicad_sch]
2025-09-30 Added design rule made v.1 of board
    [MCU Carrier Board.kicad_pcb, MCU Carrier Board.kicad_sch]
2025-10-27 for dev board carrier
    [MCU Carrier Board V1.2.kicad_pcb, MCU Carrier Board V1.2.kicad_sch]
2026-04-20 PCB version update
    [I2CConfig.kicad_sch, Modules.kicad_sch, OSMC_Receiver_Multiplexer.kicad_pcb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]
2026-04-22 Update README.md
    small changes
    replaced Onshape with Fusion under software
    added premade to the case for features
2026-04-22 Delete Hardware/Shell/OSMC_Shell2.stl
    removed way out of date model that I created
    [OSMC_Shell2.stl]
2026-04-22 Update Assembly guide.md
    Updated the Shell printing and assembly instructions
